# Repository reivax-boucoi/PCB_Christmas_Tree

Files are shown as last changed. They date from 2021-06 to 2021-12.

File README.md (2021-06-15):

# PCB Christmas Tree
This project is a simple PCB based Christmas ornament with blinky LEDs and rechargeable supercaps.

---

<div style="float:left;"> 
    tree_front
</div> 

---   

### Hardware

---

Project was done in Kicad (yay for open-source !). Project files are here: ```Hardware\Kicad\```, including the custom footprint library ```Hardware\Kicad\christmas_tree.pretty```.

#### Schematic

---

Schematic : ```Hardware\schematic.pdf```

Bill of Materials : ```Hardware\BOM.csv```

Components were chosen based on my current stock. 
* **Power storage**: Instead of traditional batteries, 2 Maxwell 10F 2.7V supercapacitors were used as rechargeable storage, just because I have a bunch of them and don't like non-rechargeable gadgets. Granted, I estimated the tree can only run about 1 hour max per charge (approx. 6mA average current draw), which is not great considering a single CR2032 could probably last several weeks. But, supercaps are fun and you can recharge them with any USB port in <1min.
* **Charging**: An integrated USB connector allows direct charging of the supercaps, through a current limiting resistor. Do not make it less than ~15Ω to not exceed USB spec current capabilities. I added an optional charge balancing circuitry with TL431 shunt Vref, but didn't used it in the end as my caps were quite similar in capacity.
* **Brain of the operations**: I used the ever popular Attiny 25/45/85 series, a small 8-bit AVR micro which offers more than enough capabilities & programming space than I need. Programming port is a TagConnect footprint modified to remove the through holes.
* **LEDs**: Given the limited amount of GPIOs on the µC, I turned to [Charlieplexing](https://en.wikipedia.org/wiki/Charlieplexing), which allows with some clever tricks to drive 12 LEDs with only 4 pins. One thing though, if you want to use different color LEDs you won't be able to adjust their individual brightness easily, so blue LEDs will be dimmer than red by example.
* **Touch button**: For extra fanciness I added a TTP223 touch sensor chip, which allows to cycle between different display modes. The default config works fine even if not populated.

#### Layout

---

To keep this project cheap, the goal was to fit the whole layout on a 10x10cm 2 layer board, which JLCPCB famously offers at 2$ for 5pcs. Decision was made to split the tree in 2 halves that would then be soldered back together, to get a bit extra height. 

For the 1st time I experimented with using the different layers (bare FR4 material, bare copper, copper+soldermask, bare soldermask and silkscreen) to make a somewhat artistic result. For more info on the colors you can get when playing with PCBs I would recommend visiting [this page](https://github.com/Hanqaqa/PCB_Color_Palette).

- Exposed pads spanning the 2 halves of the tree allow to join them and propagate the tracks for the LEDs
- Leds are reverse mounted so they shine through the board: solder mask keepout areas are placed on both sides to let the light through.
- Base of the tree doubles as a USB A port to easily recharge the batteries
- Supercapacitors provide mechanical support to stand the tree upright

<div style="float:left;"> 
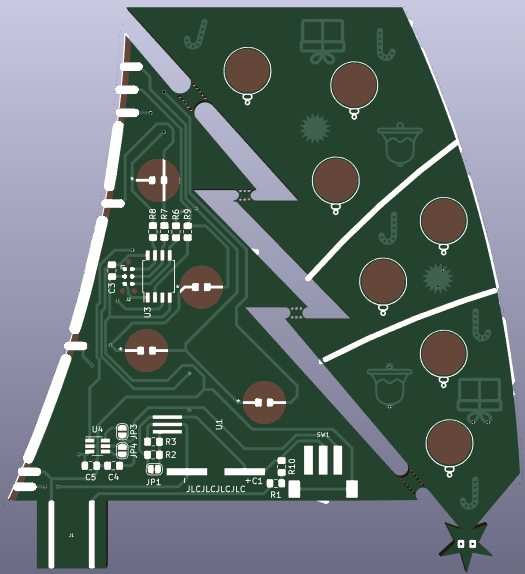
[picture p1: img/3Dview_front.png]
PCB 3D view front
    
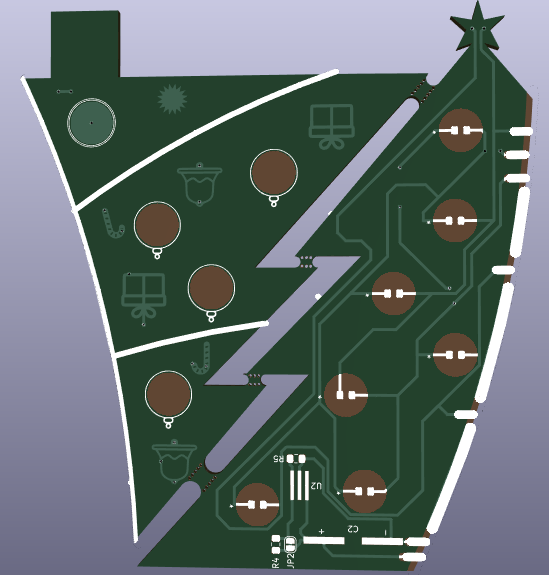
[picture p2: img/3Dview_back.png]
PCB 3D view back
    
</div> 

#### Ordering

---

Zipped gerbers are available (```Hardware\Kicad\gerbers.zip```)to be directly dropped on manufacturers websites like JLCPCB. I used their excellent prototype service for my boards, both cheap and quick.

Feel free to use these files as is or modify and improve the project. Don't forget to share our version as well!

Final dimensions are 88.7mm*98mm.

Ordering settings: 2 layers, 1.6mm board thickness, white silkscreen, HASL(with lead) surface finish, 1oz copper weight, Specify a location for Remove Order Number,

In the Remarks field: "Please note: Some parts use Solder Mask Defined Pads. Do not compensate/modify the solder mask for them. No edge plating required. Center cutout to be routed and discarded."

#### Assembly

---

<div style="float:left;"> 
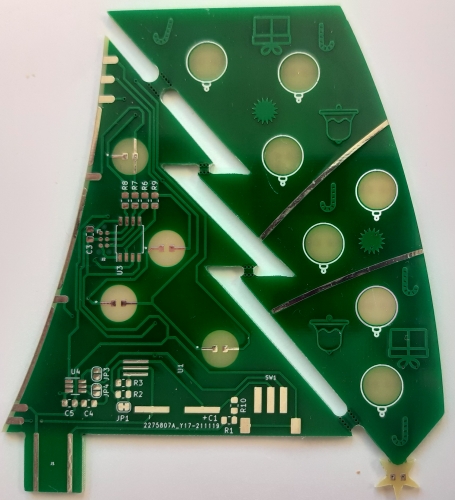
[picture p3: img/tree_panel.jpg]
tree_panel
    
    tree_separated
</div> 
The PCB comes with the 2 halves attached with mousebites. Once separated the remaining burs can be filed off.
<div style="float:left;"> 
    tree_back
    tree_front
    tree_assembled
</div> 

Minimum components to be assembled are: C1&C2 supercaps, SW1 power switch, U3 microcontroller, R1 & R10 charging resistors, the 4 220Ω resistors and the LEDs.

To avoid making a custom TagConnect to ICSP adapter, the µC can be programmed in a socket before being soldered on the board.

#### Programming

---

Precompiled version of the firmware: ```Software\main.hex```

To upload using avrdude, run the following commands : `avrdude -u -c usbtiny -p t85 -B 5 -F -U flash:w:main.hex:a -U lfuse:w:0xE2:m -U hfuse:w:0xDF:m -U efuse:w:0xFF:m`

---
---

### Software

---

Software uses Timer1 to cycle between each LED and light it using a 3 bit intensity scale.
Pin change interrupt is used for touch button sensing.
This allows the CPU to be put to sleep most of the time, reducing power consumption( ~0.75mA instead of 5.5mA !)
Several blinking modes can be cycled through with the touch button: scroll (default, up and down animation), all (all on with sligth twinkle), and pixies (one LED at a time with low duty cycle).

Depending on the animation mode used, runtime per charge can vary between 1.3 and 5.5 hours.

```Program: 922 bytes (11.3% Full) & Data: 36 bytes (7.0% Full)```

|               |      | Average consumption (mA) |              | 5                | F total capacitance             |
|---------------|------|--------------------------|--------------|------------------|---------------------------------|
|               |      | All on mode              | Economy mode | E(J)             |                                 |
| V full charge | 5    | 4.2                      | 0.9          | 62.5             | Energy when at max voltage      |
| V min working | 2.5  | 1.1                      | 0.34         | 15.625           | Energy left when at min voltage |
| V average     | 3.75 | 2.65                     | 0.62         | 46.875           | Usable energy                   |
|               |      |                          |              | 3.472            | mAh usable capacity             |
|               |      | 01h18min                 | 05h36min     | Expected runtime |                                 |

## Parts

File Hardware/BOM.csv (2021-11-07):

Qty | Reference(s) | Value | Footprint | Datasheet
2 | C1, C2 | 10F | christmas_tree:Supercap_SMD | ~
2 | C3, C4 | 100n | Capacitor_SMD:C_0805_2012Metric_Pad1.15x1.40mm_HandSolder | ~
1 | C5 | DNP | Capacitor_SMD:C_0805_2012Metric_Pad1.15x1.40mm_HandSolder | ~
1 | D1 | LED | LED_SMD:LED_0805_2012Metric_Pad1.15x1.40mm_HandSolder | ~
4 | D2, D4, D5, D7 | LED | christmas_tree:LED_0805_orb_r | ~
7 | D3, D6, D8, D9, D10, D11, D12 | LED | christmas_tree:LED_0805_orb | ~
1 | J1 | USB_A | footprints:USBA_PCB | ~
1 | J2 | Conn_01x06 | christmas_tree:Tag-Connect_noHoles | ~
1 | J3 | Touch | christmas_tree:Touch_capacitive | ~
2 | JP1, JP2 | Jumper_NC_Small | Jumper:SolderJumper-2_P1.3mm_Bridged_RoundedPad1.0x1.5mm | ~
2 | JP3, JP4 | Jumper_NO_Small | Jumper:SolderJumper-2_P1.3mm_Open_RoundedPad1.0x1.5mm | ~
2 | R1, R10 | 100 | Resistor_SMD:R_0805_2012Metric_Pad1.15x1.40mm_HandSolder | ~
2 | R2, R4 | 12k | Resistor_SMD:R_0805_2012Metric_Pad1.15x1.40mm_HandSolder | ~
2 | R3, R5 | 280k | Resistor_SMD:R_0805_2012Metric_Pad1.15x1.40mm_HandSolder | ~
4 | R6, R7, R8, R9 | 220 | Resistor_SMD:R_0805_2012Metric_Pad1.15x1.40mm_HandSolder | ~
1 | SW1 | SW_SPDT_shield | footprints:SPDT_SW_pcb_edge_mount | ~
2 | U1, U2 | TL431LP | christmas_tree:TO92_H | http://www.ti.com/lit/ds/symlink/tl431.pdf
1 | U3 | ATtiny45-20SU | Package_SO:SOIJ-8_5.3x5.3mm_P1.27mm | http://ww1.microchip.com/downloads/en/DeviceDoc/atmel-2586-avr-8-bit-microcontroller-attiny25-attiny45-attiny85_datasheet.pdf
1 | U4 | TTP223 | Package_TO_SOT_SMD:SOT-23-6_Handsoldering | https://datasheet.lcsc.com/szlcsc/TTP223-BA6_C80757.pdf

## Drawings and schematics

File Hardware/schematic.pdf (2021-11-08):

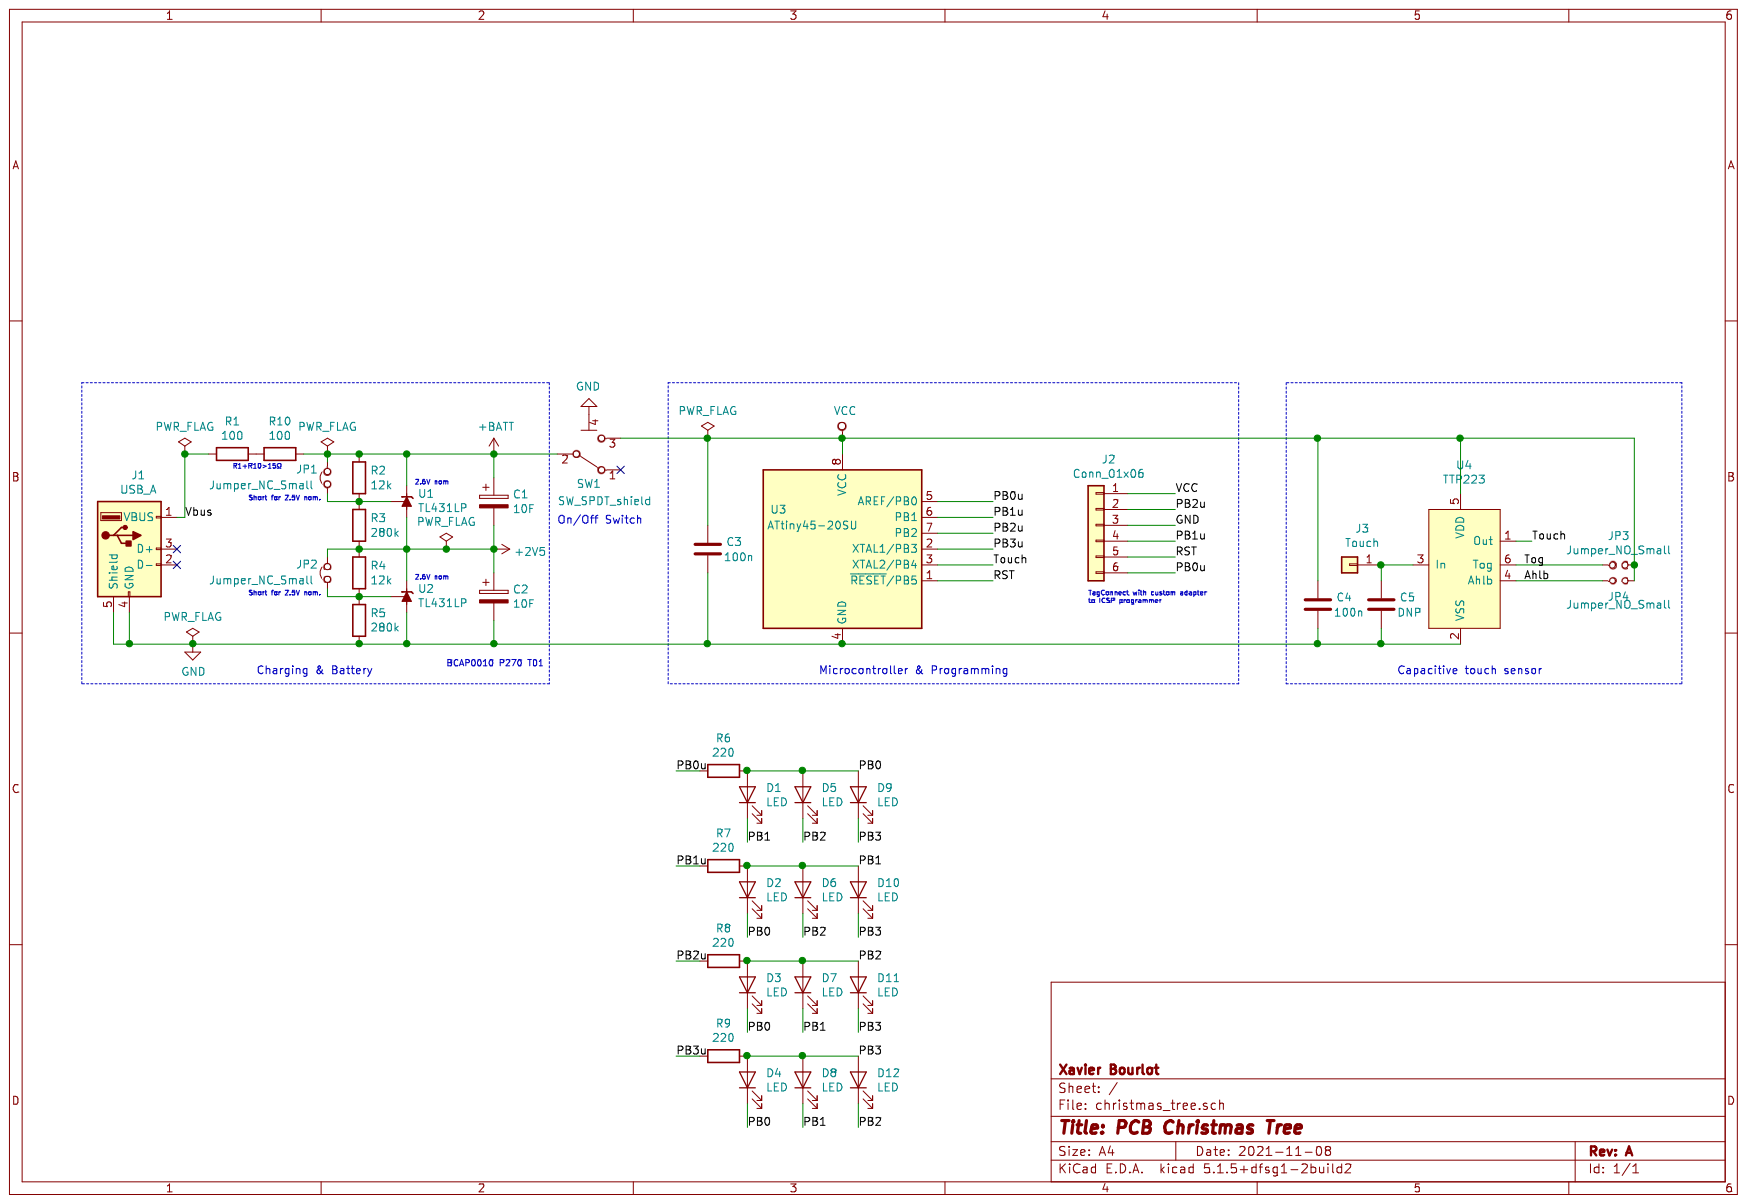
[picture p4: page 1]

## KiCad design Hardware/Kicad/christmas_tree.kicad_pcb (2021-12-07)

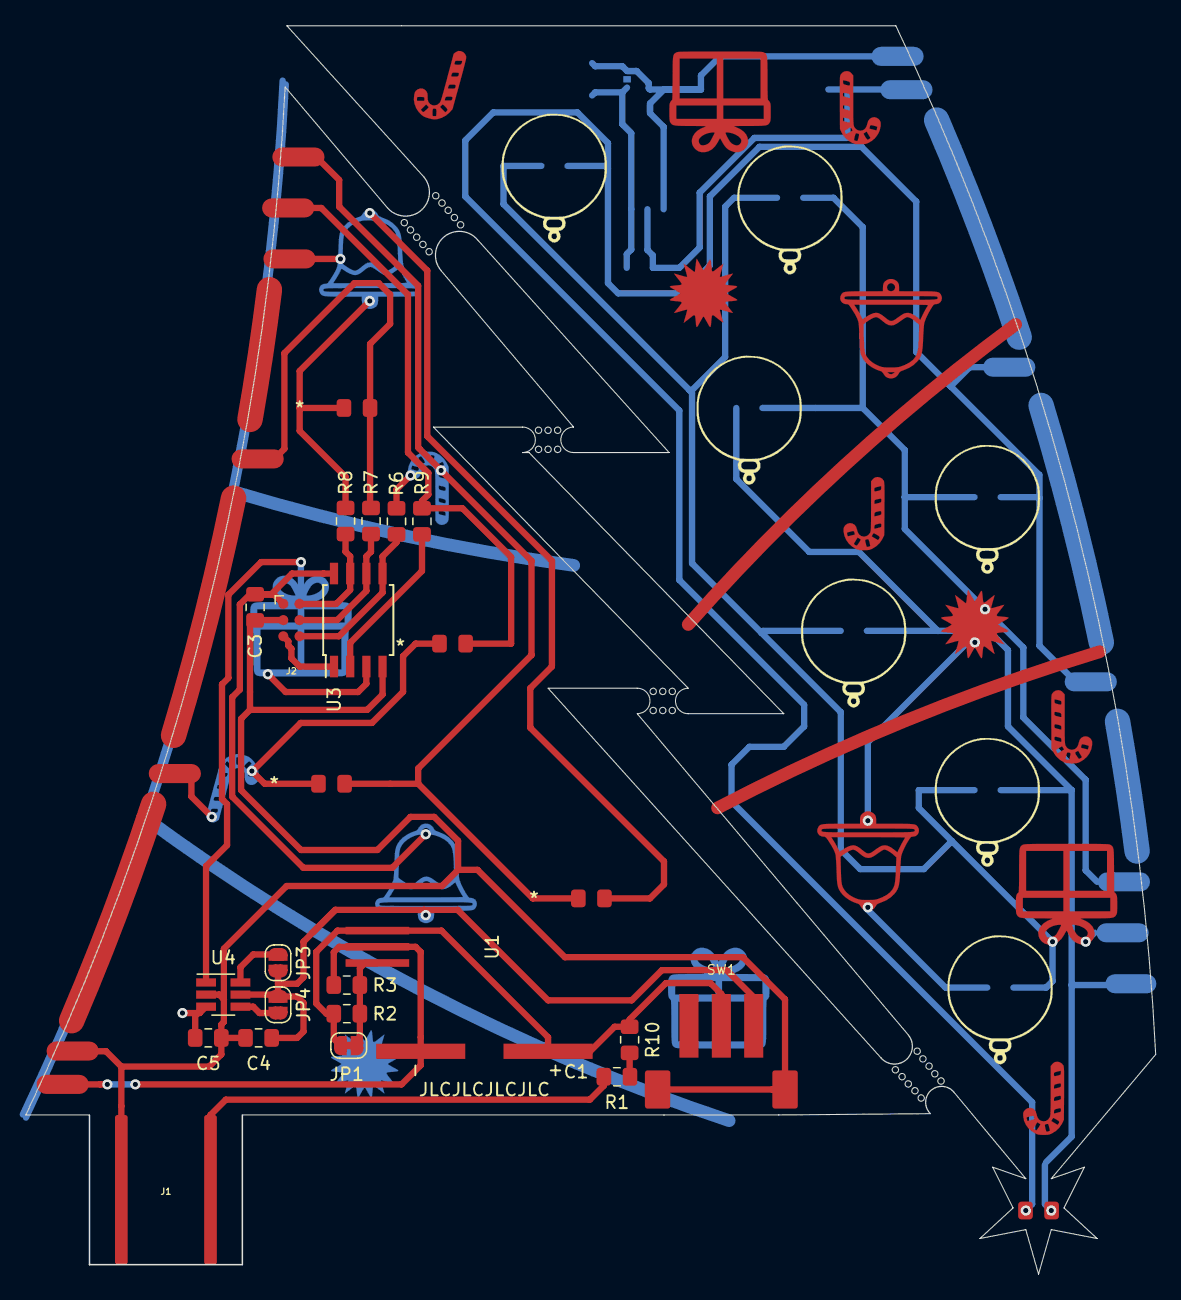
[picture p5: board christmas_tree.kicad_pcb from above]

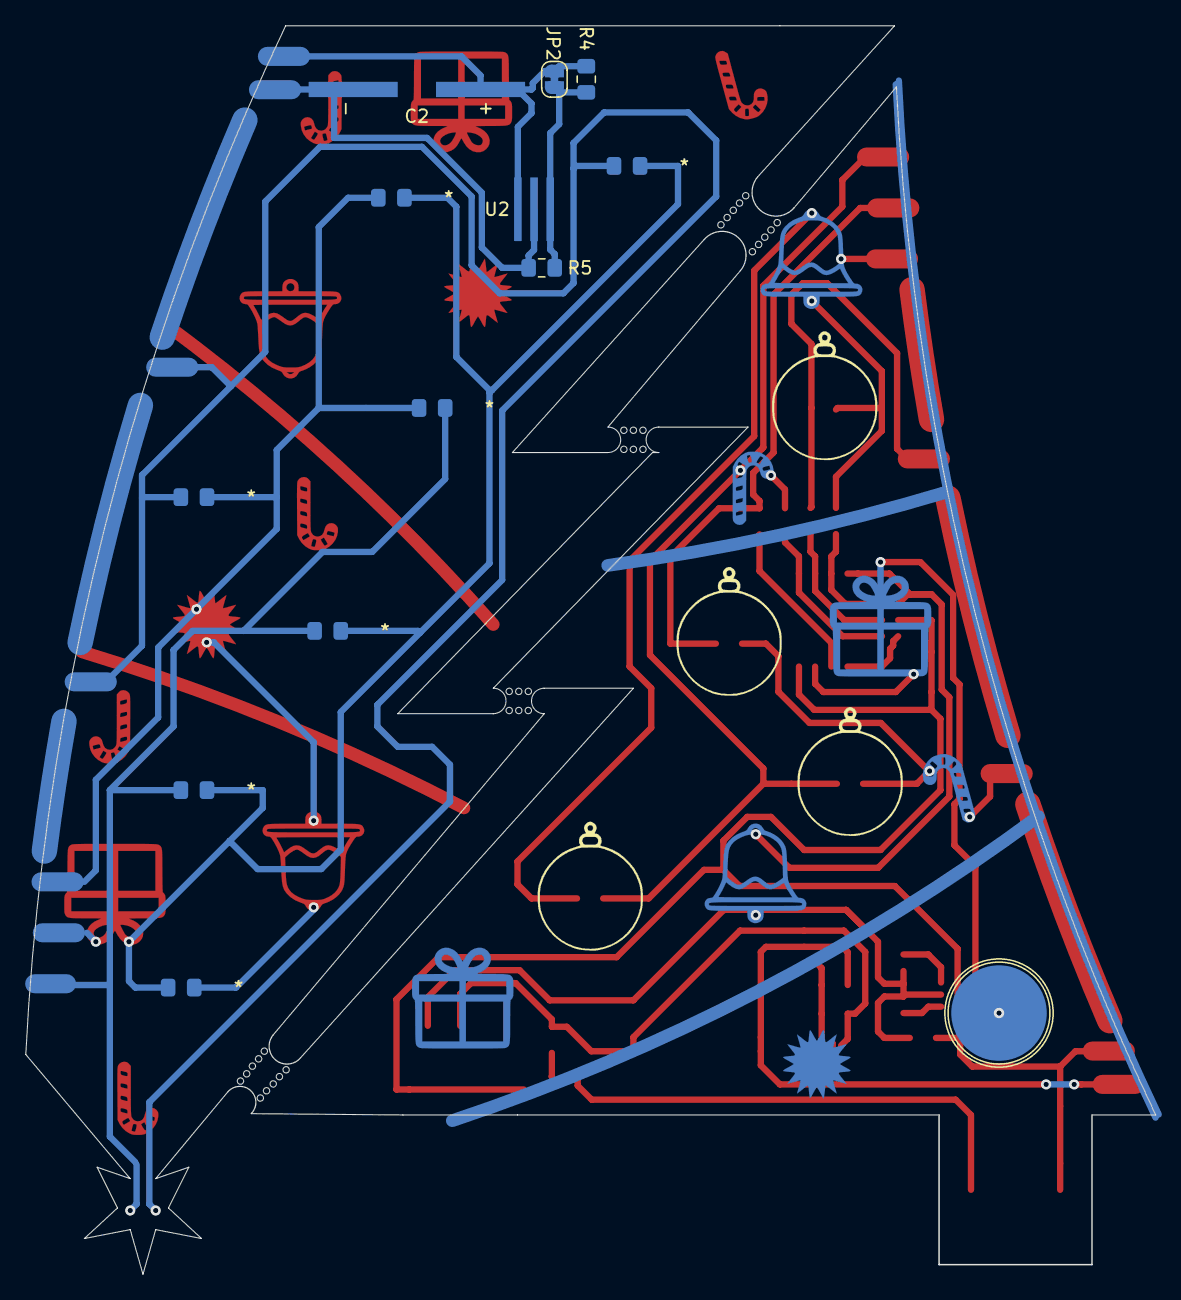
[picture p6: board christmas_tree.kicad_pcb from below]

Board: 2 copper layers, 88.7 x 98.0 mm, 43 parts (12 on the bottom side), 21 nets.

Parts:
C1, C2: 10F; Supercap_SMD
C3, C4: 100n; C_0805_2012Metric_Pad1.15x1.40mm_HandSolder
C5: DNP; C_0805_2012Metric_Pad1.15x1.40mm_HandSolder
D1: LED; LED_0805_2012Metric_Pad1.15x1.40mm_HandSolder
D2, D4, D5, D7: LED; LED_0805_orb_r
D3, D6, D8, D9, D10, D11, D12: LED; LED_0805_orb
J1: USB_A; USBA_PCB
J2: Conn_01x06; Tag-Connect_noHoles
J3: Touch; Touch_capacitive
JP1, JP2: Jumper_NC_Small; SolderJumper-2_P1.3mm_Bridged_RoundedPad1.0x1.5mm
JP3, JP4: Jumper_NO_Small; SolderJumper-2_P1.3mm_Open_RoundedPad1.0x1.5mm
R1, R10: 100; R_0805_2012Metric_Pad1.15x1.40mm_HandSolder
R2, R4: 12k; R_0805_2012Metric_Pad1.15x1.40mm_HandSolder
R3, R5: 280k; R_0805_2012Metric_Pad1.15x1.40mm_HandSolder
R6, R7, R8, R9: 220; R_0805_2012Metric_Pad1.15x1.40mm_HandSolder
SW1: SW_SPDT_shield; SPDT_SW_pcb_edge_mount
U1, U2: TL431LP; TO92_H
U3: ATtiny45-20SU; SOIJ-8_5.3x5.3mm_P1.27mm
U4: TTP223; SOT-23-6_Handsoldering
mouse-bite-2mm-slot, mouse-bite-2mm-slot#2: VAL**; mouse-bite-2mm-slot_long
mouse-bite-2mm-slot#3, mouse-bite-2mm-slot#4: VAL**; mouse-bite-2mm-slot

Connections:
+2V5: C1.2, C2.1, JP2.2, R3.2, R4.1, U1.2, U2.3
+BATT: C1.1, JP1.2, R2.1, R10.1, SW1.2, U1.3
/Ahlb: JP4.1, U4.4
/PB0: D1.2, D2.1, D3.1, D4.1, D5.2, D9.2, R6.1
/PB0u: J2.6, R6.2, U3.5
/PB1: D1.1, D2.2, D6.2, D7.1, D8.1, D10.2, R7.1
/PB1u: J2.4, R7.2, U3.6
/PB2: D3.2, D5.1, D6.1, D7.2, D11.2, D12.1, R8.1
/PB2u: J2.2, R8.2, U3.7
/PB3: D4.2, D8.2, D9.1, D10.1, D11.1, D12.2, R9.1
/PB3u: R9.2, U3.2
/RST: J2.5, U3.1
/Tog: JP3.1, U4.6
/Touch: U3.3, U4.1
/Vbus: J1.1, R1.2
GND: C2.2, C3.2, C4.2, C5.2, J1.4, J2.3, R5.2, SW1.4, U2.2, U3.4, U4.2
unnamed: C5.1, J3.1, U4.3
unnamed: JP1.1, R2.2, R3.1, U1.1
unnamed: JP2.1, R4.2, R5.1, U2.1
unnamed: R1.1, R10.2
VCC: C3.1, C4.1, J2.1, JP3.2, JP4.2, SW1.3, U3.8, U4.5

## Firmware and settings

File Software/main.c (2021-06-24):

#include <avr/io.h>
#include <util/delay.h>
#include<avr/interrupt.h>
#include <avr/sleep.h>
#include <avr/power.h>

#define ALL 0
#define PIXIE 1
#define SCROLL 2
#define DEBUG 3
#define NB_MODES 3

#define TOUCH_FLAG 0
//#define ADC_FLAG 1
#define DEBUG_FLAG 2
#define DIR_FLAG 2

volatile uint8_t cnt=1;
volatile uint8_t level[12];

//Select order based on led soldering polarity
const uint8_t order[12] = {0,11,9,4,2,10,7,6,3,1,8,5};//Reverse mounted leds ordering
//const uint8_t order[12] = {3,8,2,7,9,4,5,1,0,6,11,10};//Right orientation for leds

volatile uint8_t blinkMode = SCROLL;    //Default animation at powerup
volatile uint8_t pstate=0;

/*
//unused random functions
static	long	randx;
static	char	randf;

void srand(unsigned x){
	randx = x;
	randf = 1;
}

int rand(void){
	if(!randf)srand(1);
	return((int)((randx = randx*1103515245L + 12345)>>16) & 077777);
}
*/
volatile uint8_t brightness=5;
volatile uint8_t speed=15;
volatile uint8_t index=1;


int main(void){
      
    //Timer1 for LED charlieplexing
    TCCR1=(1<<CTC1)|(1<<CS11);  //Divide clock by 1, was 2<<CS10
    GTCCR=0;                    //No PWM
    OCR1A=0;                    //No PWM
    OCR1C=250-1;                //16kHz for good POV (16k/64/12=20Hz)
    TIMSK|=(1<<OCIE1A);         //Compare Match A interrupt
    
    /*
    //Second timer to handle animations/ADC sampling. Unused
    TCCR0A=(1<<WGM01);
    OCR0A=255;
    TCCR0B=(1<<CS02)|(1<<CS00);
    TIMSK|=(1<<OCIE0A);
    */
    /*
    //ADC for supply voltage brightness compensation, unused for now
    ADMUX=(1<<MUX3)|(1<<MUX2);
    ADCSRA |= (1<<ADEN) | (1<<ADIE);
    */
    
    //Enable pin change interrupt for touch button to wake CPU out of idle mode
    PCMSK|=(1<<PCINT4);
    GIMSK|=(1<<PCIE);
    
    //save power by disabling unused peripherals
    ADCSRA&=~(1<<ADEN);
    power_adc_disable();
    power_timer0_disable();
    power_usi_disable();
    
    sei();           //Enable interrupts
    while(1){
        
        set_sleep_mode(SLEEP_MODE_IDLE);//put micro to sleep on interrupts are done
        sleep_mode();
/*
        if(pstate&(1<<ADC_FLAG)){
            pstate&=~(1<<ADC_FLAG);   
            ADCSRA |= (1<<ADSC);
        }*/

    }
    return 0;
}     
/*
ISR(ADC_vect){
    uint16_t res=ADCL;
    res|=(ADCH<<8);
    blinkMode=2753/res-3;   //Vcc=1024*1.1/ADC
}*/
/*
ISR(TIM0_COMPA_vect) {
    
}*/

ISR(PCINT0_vect){   //Touch button Pin Change Interrupt
    if((PINB&(1<<PINB4)) && (pstate&(1<<TOUCH_FLAG))){
        pstate&=~(1<<TOUCH_FLAG);   
        blinkMode++;
        if(blinkMode>=NB_MODES)blinkMode=0;
        brightness=0;
        pstate|=(1<<DIR_FLAG);
        index=0;
        for(uint8_t i=0;i<12;i++){
            level[i]=0;
        }
    }else if(!(PINB&(1<<PINB4)) && !(pstate&(1<<TOUCH_FLAG))){
        pstate|=(1<<TOUCH_FLAG);            
    }
}


ISR(TIM1_COMPA_vect) {  //Charlieplexing and animation interrupt
    
    //Charlieplexing stuff on a 3bit scale (brightness ranges from 0 to 7
    static uint8_t first, ramp, column, bits, colbit;
    ramp = (ramp+1) & 0x07;
    if (ramp == 0) {
        bits = 0x07;
        column = (column + 1) & 0x03;
        first = column * 3;
        colbit = 1<<column;
    }
    if (level[first] == ramp) bits = bits & 0x06;
    if (level[first+1] == ramp) bits = bits & 0x05;
    if (level[first+2] == ramp) bits = bits & 0x03;
    uint8_t mask = colbit - 1;
    uint8_t outputs = (bits & mask) | (bits & ~mask)<<1;
    DDRB = (DDRB & 0xF0) | outputs | colbit;
    PORTB = (PORTB & 0xF0) | outputs;
    
    //Animation stuff
    cnt++;
    if(cnt==speed){
        cnt=0;
    switch(blinkMode){  //animate differently based on animation mode
        
        case SCROLL:
            if(pstate&(1<<DIR_FLAG)){
                level[order[index]]=brightness++;
                if(brightness>7){
                    brightness=0;
                    index++;
                    if(index>11){
                        index=11;
                        brightness=7;
                        pstate&=~(1<<DIR_FLAG);
                    }
                }
            }else{
                level[order[index]]=brightness--;
                if(brightness==0){
                    brightness=7;
                    index--;
                    if(index==0){
                        index=0;
                        brightness=0;
                        pstate|=(1<<DIR_FLAG);
                    }
                }
            }
            break;
            
        case ALL:
            level[order[index]]=brightness;
            brightness=(brightness+1)&0x07;
            if(brightness==0){
                //level[order[index]]=0;
                index++;
                if(index>11)index=0;
            }
            break;
            
        case PIXIE: //light 1 led at a time, 1/10th duty cycle. Use raw level array so the order appears random
            switch(++brightness){
                case 1:
                    level[index]=7;
                break;
                case 2:
                    level[index]=0;
                break;
                case 10:
                    brightness=0;
                    index++;
                    if(index>11)index=0;
            }

        case DEBUG:
            break;
        default:
            break;
        }
    }
}

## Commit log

2021-11-06 added img
    [christmas_tree.kicad_pcb, christmas_tree.sch]
2021-11-08 added schematic
2021-11-16 added zipped Gerbers
2021-11-29 added led polarity on DWG.user layer
2021-12-07 added prog
    [christmas_tree.kicad_pcb]
